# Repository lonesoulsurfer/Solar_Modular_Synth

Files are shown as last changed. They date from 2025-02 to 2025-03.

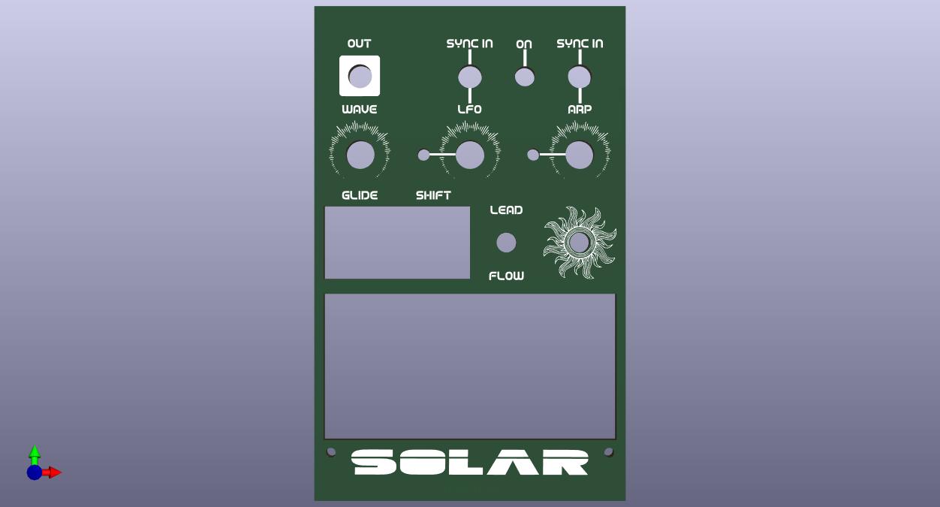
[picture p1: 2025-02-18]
Front Panel Design/Solar Front Panel.jpg

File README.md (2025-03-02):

g

# Solar Modular Synth
 A modular synth based around Arduino
First and foremost - a big shoutout to the creative team over at [Bleep Labs](https://bleeplabs.com/) for the original build which is called the Neblophone.

I wanted to be able to add some playability to the little modular synth that I'm putting together and after a extensive search on Google I stumbled on the Neblophone which I have re-named 'Solar' for this build.

The main changes that I have implemented are; I changed the stylus style keyboard over to actual momentary switches, I designed a front panel and custom PCB which can be used in Eurorack modules (or as a fun standalone synth) and lastly, added 2 sync inputs so you can connect it to other synths.

The sync inputs can be a little fiddily but once tuned in work great.  However, you don;t have to sync in the synth as you can just play it over the top of whatever you are jamming to.

So what are the features of the little synth?

– Eight waveforms

– Light controlled (Vactrol) analog low-pass filter with five adjustable LFO LED modes.

– Perfect tuning across six octaves.

– Adjustable temperament and key.

– Six arpeggio modes with adjustable rate.

The main goal with building this module is to create my own 'simple to build' modular synth. I wanted to keep everything as easy as possble with each module built with the following aims:

-   Can be powered by 9V (and 12V)

-   Easy to build with minimum components

-   Use Arduino to keep it simple (plus it helps to keep the components down and everything in tune)

-   Can fit into any modular synth Eurorck (include the ability to power the module via normal module power sources)

-   Has to sound great!

It's the first time that I have utilized cherry MX switches and I'm so glad that I used them! 
Lastly, as I have mentioned above, Solar makes a fun standalone synth and has been designed to be able to fit in Eurorack modules and powered via a Eurorack power supply!

I have also completed a step by step guide which you can find on Instructables

YouTube vid can be found below
https://www.youtube.com/watch?v=ggaYos6u02A

e

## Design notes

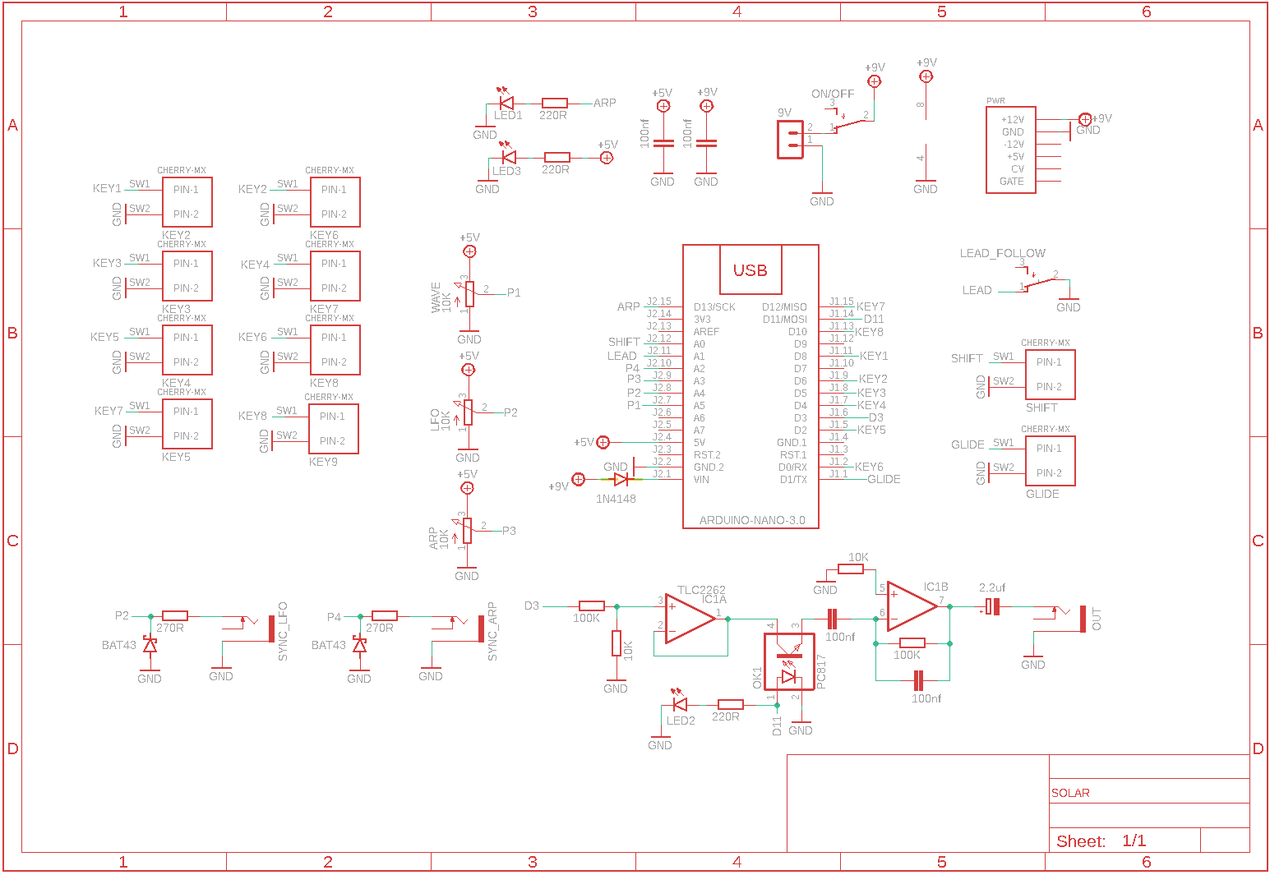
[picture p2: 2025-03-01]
schematic.png

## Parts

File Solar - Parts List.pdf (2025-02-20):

Part | Name | Type | Size | Value | Qty | Image Link

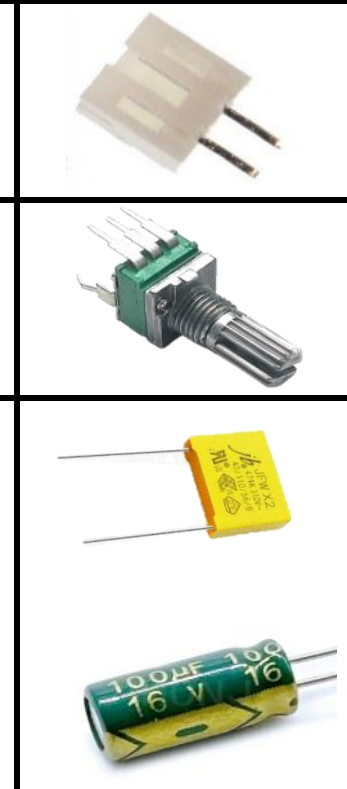
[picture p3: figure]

JST Connector | | Vertical - 2P | 2.0mm | | | Ali Express (https://www.aliexpress.com/w/wholesale-jst-connector-2.0-2P.html?spm=a2g0o.productlist.search.0)
Potentimeter | | Vertical | 9mm | 10K | 3 | Ali Express (https://www.aliexpress.com/w/wholesale-potentiometer-verticle-9mm.html)
Capacitor | | Polyester plastic electrolyte radial | | 100nf 2.2uf | 4 1 | Ali Express (https://www.aliexpress.com/w/wholesale-capacitor-polyester-plastic-.html) Ali Express (https://www.aliexpress.com/w/wholesale-capacitor-electrolytic-radial.html)
Diode | Bat43 1N4148 | Schottky | | | 2 1 | Ali Express (https://www.aliexpress.com/w/wholesale-bat43-diode.html?spm=a2g0o.detail.search.0) Ali Express (https://www.aliexpress.com/w/wholesale-1N4148-.html?spm=a2g0o.detail.search.0)
Swich | Cherry MX Cherry MX Caps Toggle switch | stitch type for PCB | | | 10 10 2 | Ali Express (https://www.aliexpress.com/w/wholesale-cherry-mx.html?spm=a2g0o.productlist.search.0) Ali Express (https://www.aliexpress.com/w/wholesale-cherry-mx-caps.html?spm=a2g0o.productlist.search.0) Ali Express (https://www.aliexpress.com/item/1005001510219617.html)
IC | TLC2262 | Op amp | 8 pin | | 1 | Ali Express (https://www.aliexpress.com/w/wholesale-TLC2262.html?spm=a2g0o.detail.search.0)

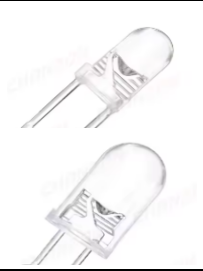
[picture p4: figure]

LED | | Any colour Yellow (or whatever colour you want) | 3mm 5mm | | 2 1 | Ali Express (https://www.aliexpress.com/w/wholesale-led-3mm.html?spm=a2g0o.detail.search.0) Ali Express (https://www.aliexpress.com/w/wholesale-5mm-led.html?spm=a2g0o.detail.search.0)

Part | Name | Type | Size | Value | Qty | Image Link

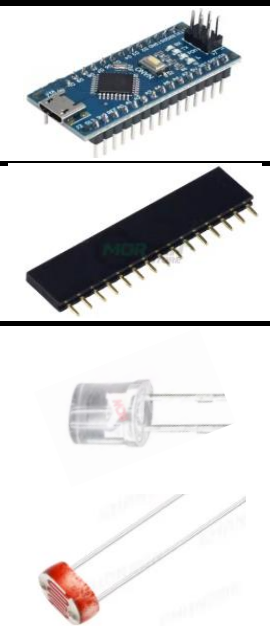
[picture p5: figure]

Arduino | Nano | Clone will work fine | | | 1 | Ali Express (https://www.aliexpress.com/w/wholesale-arduino-nano.html?spm=a2g0o.productlist.search.0)
Female Header Pins | | | 15 | | 2 | Ali Express (https://www.aliexpress.com/w/wholesale-header-pin-15-female.html?spm=a2g0o.detail.search.0)
Vactrol | LED photoresistor heat shrink | Flat head - white | 5mm 5 to 6mm | | 1 1 1 | Ali Express (https://www.aliexpress.com/w/wholesale-led-5mm-flat-head.html?spm=a2g0o.detail.search.0) Ali Express (https://www.aliexpress.com/w/wholesale-photoresistor.html?spm=a2g0o.detail.search.0) Ali Express (https://www.aliexpress.com/w/wholesale-heat-shrink-5mm.html?spm=a2g0o.detail.search.0)
Audio jack | PJ-301M | Vertical - pins should be PCB style | 3.5mm | | 3 | Ali Express (https://www.aliexpress.com/w/wholesale-PJ301M.html?spm=a2g0o.productlist.search.0)
Resistors | | metal film | 0.25W 1% | 100K 10K 220R 270R | 2 2 3 2 | Ali Express (https://www.aliexpress.com/w/wholesale-resistor-metal-film-assorted.html)

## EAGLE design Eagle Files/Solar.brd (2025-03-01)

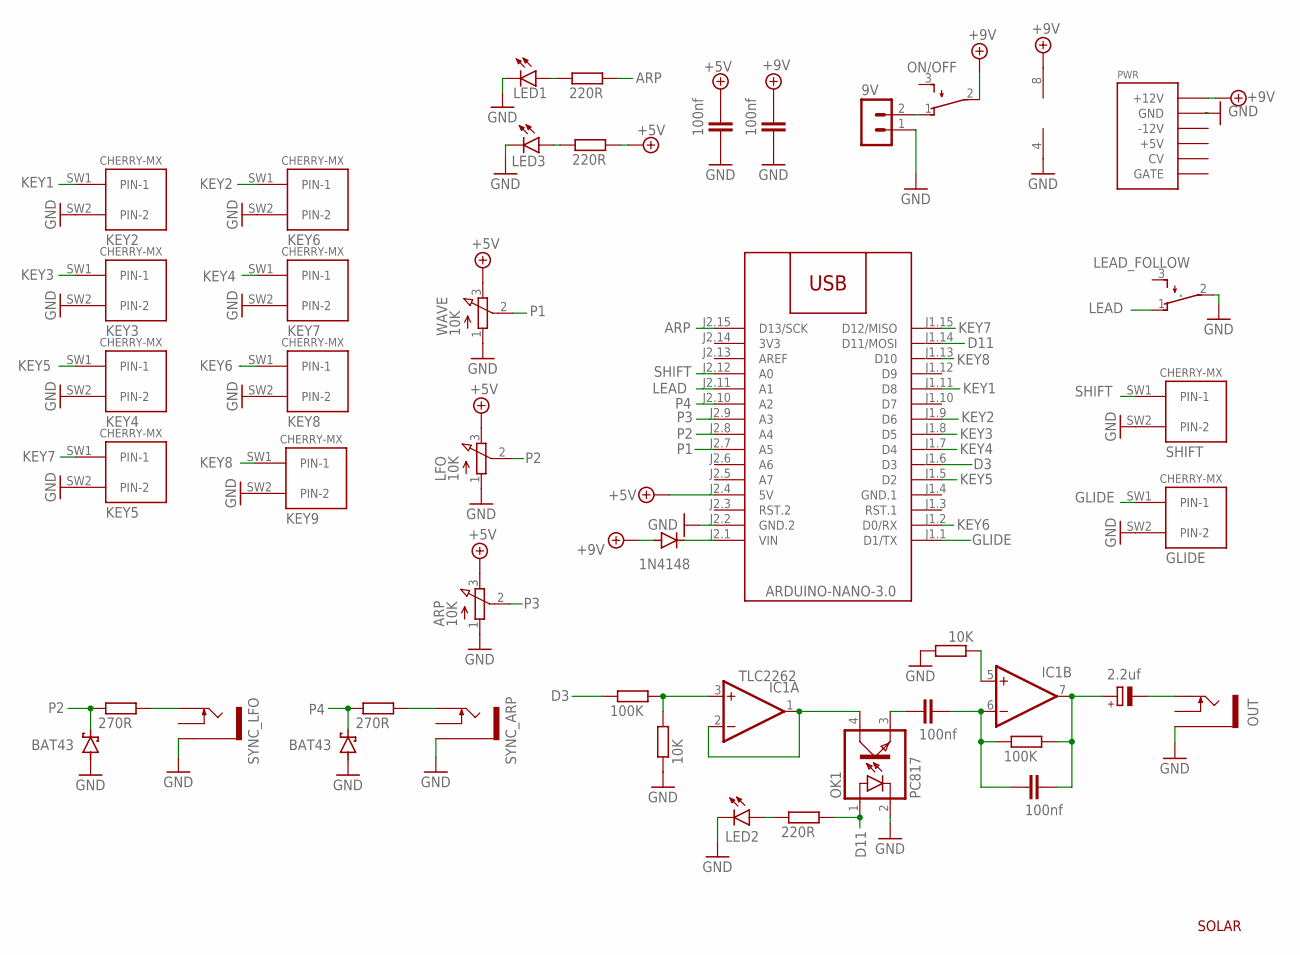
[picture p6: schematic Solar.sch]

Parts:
9V: B2B-PH-K-S
ARP: 10K; EVUFXL
C1, C2, C3, C5: 100nf; C050-024X044
C4: 2.2uf; E2,5-6E
D1, D3: BAT43; DO35-10
D2: 1N4148; DO35-7
GLIDE: CHERRY-MX
IC1: TLC2262; DIL08
KEY2, KEY3, KEY4, KEY5, KEY6, KEY7, KEY8, KEY9: CHERRY-MX
LEAD_FOLLOW: TL32PO; TL3XPO
LED1, LED2: LED3MM
LED3: LED5MM
LFO: 10K; EVUFXL
M1: ARDUINO-NANO-3.0
OK1: PC817; DIL04
ON/OFF: TL32PO; TL3XPO
OUT: THONKICONNNEW; WQP-PJ301M-12_JACK
PWR: POWER; POWER_16
R1, R3: 100K; 0207/10
R2, R4: 10K; 0207/10
R5, R8, R10: 220R; 0207/10
R6, R7: 270R; 0207/10
SHIFT: CHERRY-MX
SYNC_ARP: THONKICONNNEW; WQP-PJ301M-12_JACK
SYNC_LFO: THONKICONNNEW; WQP-PJ301M-12_JACK
WAVE: 10K; EVUFXL

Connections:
3V3: M1.J2.14 (3V3)
+5V: ARP.3 (E), C5.2, LFO.3 (E), M1.J2.4 (5V), R5.2, WAVE.3 (E)
+9V: C2.2, D2.A, IC1.8 (V+), ON/OFF.2, PWR.9 (+12V), PWR.10 (+12V)
ARP: M1.J2.15 (D13/SCK), R8.2
D3: M1.J1.6 (D3), R1.1
D11: M1.J1.14 (D11/MOSI), OK1.1 (A), R10.2
GLIDE: GLIDE.SW1 (PIN-1), M1.J1.1 (D1/TX)
GND: 9V.1, ARP.1 (A), C2.1, C5.1, D1.A, D3.A, GLIDE.SW2 (PIN-2), IC1.4 (V-), KEY2.SW2 (PIN-2), KEY3.SW2 (PIN-2), KEY4.SW2 (PIN-2), KEY5.SW2 (PIN-2), KEY6.SW2 (PIN-2), KEY7.SW2 (PIN-2), KEY8.SW2 (PIN-2), KEY9.SW2 (PIN-2), LEAD_FOLLOW.2, LED1.K (C), LED2.K (C), LED3.K (C), LFO.1 (A), M1.J2.2 (GND.2), OK1.2 (C), OUT.P$3_SLEEVE (SLEEVE), PWR.3 (GND), PWR.4 (GND), PWR.5 (GND), PWR.6 (GND), PWR.7 (GND), PWR.8 (GND), R2.1, R4.2, SHIFT.SW2 (PIN-2), SYNC_ARP.P$3_SLEEVE (SLEEVE), SYNC_LFO.P$3_SLEEVE (SLEEVE), WAVE.1 (A)
GND.1: M1.J1.4 (GND.1)
KEY1: KEY2.SW1 (PIN-1), M1.J1.11 (D8)
KEY2: KEY6.SW1 (PIN-1), M1.J1.9 (D6)
KEY3: KEY3.SW1 (PIN-1), M1.J1.8 (D5)
KEY4: KEY7.SW1 (PIN-1), M1.J1.7 (D4)
KEY5: KEY4.SW1 (PIN-1), M1.J1.5 (D2)
KEY6: KEY8.SW1 (PIN-1), M1.J1.2 (D0/RX)
KEY7: KEY5.SW1 (PIN-1), M1.J1.15 (D12/MISO)
KEY8: KEY9.SW1 (PIN-1), M1.J1.13 (D10)
LEAD: LEAD_FOLLOW.1 (O), M1.J2.11 (A1)
unnamed: LED1.A, R8.1
unnamed: 9V.2, ON/OFF.1 (O)
unnamed: IC1.3 (+IN), R1.2, R2.2
unnamed: R7.2, SYNC_LFO.P$1_TIP (TIP)
unnamed: IC1.1 (OUT), IC1.2 (-IN), OK1.4 (COL)
unnamed: C1.1, OK1.3 (EMIT)
unnamed: C1.2, C3.1, IC1.6 (-IN), R3.1
unnamed: IC1.5 (+IN), R4.1
unnamed: C3.2, C4.+, IC1.7 (OUT), R3.2
unnamed: C4.-, OUT.P$1_TIP (TIP)
unnamed: LED3.A, R5.1
unnamed: R6.2, SYNC_ARP.P$1_TIP (TIP)
unnamed: LED2.A, R10.1
unnamed: D2.C, M1.J2.1 (VIN)
P1: M1.J2.7 (A5), WAVE.2 (S)
P2: D1.C, LFO.2 (S), M1.J2.8 (A4), R7.1
P3: ARP.2 (S), M1.J2.9 (A3)
P4: D3.C, M1.J2.10 (A2), R6.1
SHIFT: M1.J2.12 (A0), SHIFT.SW1 (PIN-1)

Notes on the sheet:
SOLAR

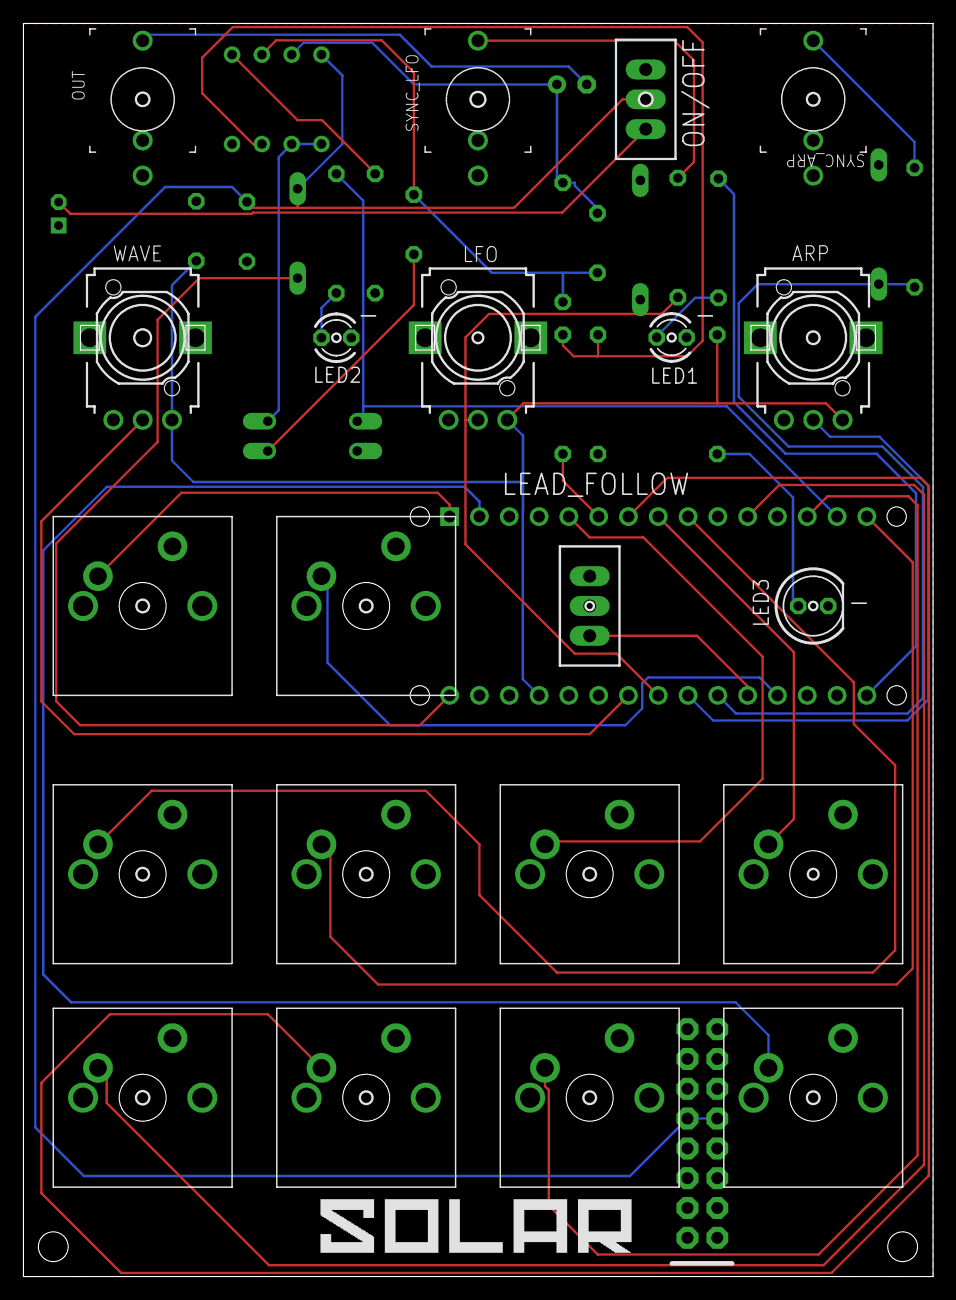
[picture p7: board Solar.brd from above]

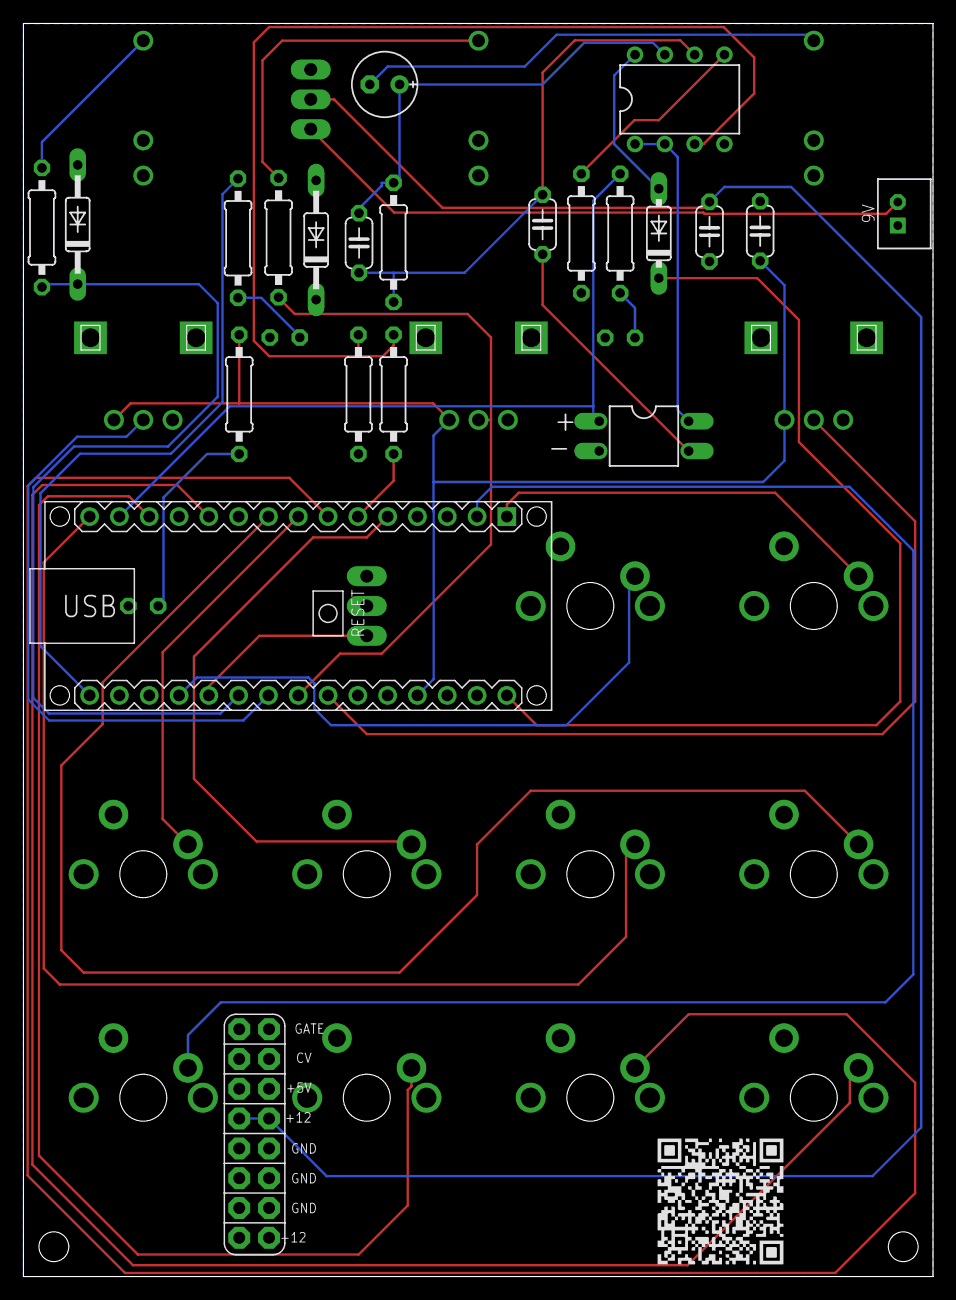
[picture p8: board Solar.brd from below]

Board: 2 copper layers, 77.5 x 106.8 mm, 43 parts (22 on the bottom side), 35 nets.

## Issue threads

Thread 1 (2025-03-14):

(Feature request) Add some way to play the device with an external controller.

rl2939, 2025-03-14:
## Problem:

Right now, the only way to play _Solar_ is by pressing the keys on the device. It is not possible to play the device from a keyboard or external sequencer.

## Solution:
Add ports to play the device from a keyboard or external sequencer. Some ideas include:
- 1v/oct and gate in ports
- MIDI port

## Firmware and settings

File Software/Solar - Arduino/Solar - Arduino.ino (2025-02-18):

/*

 NEBULOPHONE code v11 by Dr. Bleep
 
This code has not changed much since it was released mid 2011. It's very gnarly and amature and kinda embarrassing now but it did the thing!
It was my first big Arduino project and I coundn't have done it without these resources:

DDS:
 http://mouro.info/signal-generator-using-arduino-and-dds/
 http://interface.khm.de/index.php/lab/experiments/arduino-dds-sinewave-generator/
 http://www.analog.com/library/analogdialogue/archives/38-08/dds.html

Setting up timers.
 http://www.cs.mun.ca/~rod/Winter2007/4723/notes/timer0/timer0.html
 http://arcfn.com/2009/07/secrets-of-arduino-pwm.html
 http://blog.wingedvictorydesign.com/2009/05/29/generate-real-time-audio-on-the-arduino-using-pulse-code-modulation/2/

Also good to know:
 http://billgrundmann.wordpress.com/2009/03/03/to-use-or-not-use-writedigital/

BUT
My DIY noise guides and classes on using the Teensy to make synths are a better place to start these days. 
https://github.com/BleepLabs/Bleep-wiki/wiki
https://github.com/BleepLabs/dadageek-April-21/wiki

 */
#include <avr/pgmspace.h>
//#include <MemoryFree.h>

unsigned long chromatic[] = {

  2750, 2914, 3087, 3270, 3465, 3671, 3889, 4120, 4365, 4625, 4900, 5191, 5500, 5827, 6174, 6541, 6930, 7342, 7778,
  8241, 8731, 9250, 9800, 10383, 11000, 11654, 12347, 13081, 13859, 14683, 15556, 16481, 17461, 18500, 19600,
  20765, 22000, 23308, 24694, 26163, 27718, 29367, 31113, 32963, 34923, 36999, 39200, 41531, 44000, 46616, 49388,
  52325, 55437, 58733, 62225, 65926, 69846, 73999, 78399, 83061, 88000, 93233, 98777, 104650, 110873, 117466,
  124451, 131851, 139691, 147998, 156798, 166122, 176000, 186466, 197553, 209300, 221746, 234932, 248902, 263702,
  279383, 295996, 313596, 332244, 352000, 372931, 395107, 418601

};
int scale[] = {
  0, 2, 4, 5, 7, 9, 11, 12, 14, 16, 17, 19, 21, 23, 24, 26, 28, 29, 31, 33, 35, 36, 38, 40, 41, 43, 45, 47, 48, 50, 52, 53, 55, 57, 59, 60, 62, 64
};


unsigned long counter, cprev1, cprev2;
unsigned long freq, freq2, keyfreq;

byte n = 1;
int keypress, kh, prevkh2, prevkeypress2;
int prevn;
int prevkeypress, prevattackmode;
int keyr1, keyr0, keyra, keyrw, keyrw2;
int waveselect, subwaveselect, prevwavepot;
int r, r2;
int i = 1;
long prev;
long prev4;

int irin;
int irout;
long irtempo;
int ir = 0;
long previrtempo = 1;
long previr = 0;
int arpselect;
byte count = 0;
int a = 0;
int key = 1;
int d;
int s;
int lforate;
int lforateC;
int lfo = 0;
int l = 0;
int j = 10;
int r3;
byte dronemode = 3;
byte dronemodebutton, prevdronemodebutton;
int irtempomod;
int irswitch;
int arprate = 10;
int arprateF;
int arprateL;
int keyoffset = 0;

byte scan = 1;
byte shiftbutton;
byte prevshiftbutton;
int shift = 0;
int maxrelease = 250;
int maxbrightness = 84;
int keym;
int prevarprateF;
int glide = 3;
byte keyp;
byte keyc;
int remember[2];
int h = 0;
long frequencyout;
long frequencyp;
long g;
long  f;
int gliderate;
long prev9;
int k;
int glidebutton;
int prevglidebutton;
int c = 1;
int b;
int maxwaveindex = 15;
int temp;
int release, releasem, releaseb;
int releaselength;
int ampholder = 1;
int previrin;
static int oscc, oscx, oscy, oscz, oscb, oscxb;
float amp = 1;
int wavepot, arppot, lfopot;
int himap, lowmap, lowf, hif, himap2, lowmap2;
int pwmPin = 3;
int ampm, ampb, read0, read1;
int arpcount, arp;
volatile unsigned long accumulator = 0;
volatile unsigned long accumulator2 = 0;
volatile unsigned long accumulator3 = 0;
volatile unsigned long accumulator4 = 0;
volatile unsigned long accumulator5 = 0;
volatile unsigned long increment = 0;
volatile unsigned long increment2 = 0;
volatile unsigned long increment3 = 0;
volatile unsigned long increment4 = 0;
volatile unsigned long increment5 = 0;
volatile unsigned long increment6 = 0;
volatile unsigned long increment7 = 0;


long prev8;
int incrementb = 0;
unsigned long holder4;
unsigned long holder3;
unsigned long holder2;
unsigned long holder;
int offx;
byte index = 0;
byte index2 = 0;
byte index3 = 0;
byte index4 = 0;
byte indexb = 0;
byte index5 = 0;
long frequency, frequencyc, frequency2, frequency2c, frequencyouta, frequencycs, frequencyps, temppot;
int rint, indexi;
int noise = 0;
int wrc, cnw, apot, waveB, waveoff;
float bpotf;
int drone;
int acc = 8;
int oscmode = 1;
int ircount;
//long tempobank[4];
int aread, oscsel;
int oscswitch = 1;
uint16_t osc, oscj, uosc, wr, wr2, rosc, bswitch;
int xpot;
int up = 1;
int tempermentbutton, shiftcount;
int temperment = 1;
int offsetpot = 5;
int keypot = 0;
int keypotm = 0;
int tunemode = 0;
int attackmode;
int attacklength;
int upa = 1, upb = 1, upc = 1;
int toplatcha = 0;
int attackon = 0;
unsigned long prev2, prev3;
int keydown, counta, prevkeydown;
//long tune;
int maxarp = 306;
unsigned long frequencya, frequencyw, frequencyw2;
int attackp;
long attacka, attackw, wavemod;
long gstep;
unsigned int lfsr = 1;
unsigned int lfsr2 = 1;
unsigned bitholder, bitholder2;
volatile byte icnt1, icnt2, ms, noisecount;
int keysb, keysd, keypressb, keypressd, prevkeypressb, prevkeypressd, prevkh;
int scount;
int gauge, spd;
long sprev;
int restbutton = 1,      recordbutton = 1, prevrestbutton,      prevrecordbutton ;
int record, rcount = 1, recordlatch, prevrcount, resta = 0;
int recordbank[32] = {2, 63, 5, 63, 10, 63, 5, 63, 1, 63, 63, 63, 10, 63, 63, 63};
int rplace, rest = 0, rstop = 8, prevrecord;
byte bhold;
volatile long whatok, whatno;
int i1, i2, i3, i4, tria;
byte b1, b2, b3, b4;
int epot, dswitch, noisekey, rarp;
long fpot, bpot, gpot, recordinput;
long thecount;
const  char  waveTable[] PROGMEM =


{
  0, 0, 0, 0, 0, 0, 0, 0, 0, 0, 0, 0, 0, 0, 0, 0, 0, 0, 0, 0, 0, 0, 0, 0, 0, 0, 0, 0, 0, 0, 0, 0, 0, 0, 0, 0, 0, 0, 0, 0, 0, 0, 0, 0, 0, 0, 0, 0, 0, 0, 0, 0, 0, 0, 0, 0, 0, 0, 0, 0, 0, 0, 0, 0,
  0, 0, 0, 0, 0, 0, 0, 0, 0, 0, 0, 0, 0, 0, 0, 0, 0, 0, 0, 0, 0, 0, 0, 0, 0, 0, 0, 0, 0, 0, 0, 0, 0, 0, 0, 0, 0, 0, 0, 0, 0, 0, 0, 0, 0, 0, 0, 0, 0, 0, 0, 0, 0, 0, 0, 0, 0, 0, 0, 0, 0,
  0, 0, 0, 0, 0, 0, 0, 0, 0, 0, 0, 0, 0, 0, 0, 0, 0, 0, 0, 0, 0, 0, 0, 0, 0, 0, 0, 0, 0, 0, 0, 0, 0, 0, 0, 0, 0, 0, 0, 0, 0, 0, 0, 0, 0, 0, 0, 0, 0, 0, 0, 0, 0, 0, 0, 0, 0, 0, 0, 0, 0,
  0, 0, 0, 0, 0, 0, 255, 255, 255, 255, 255, 255, 255, 255, 255, 255, 255, 255, 255, 255, 255, 255, 255, 255, 255, 255, 255, 255, 255, 255, 255, 255, 255, 255,
  255, 255, 255, 255, 255, 255, 255, 255, 255, 255, 255, 255, 255, 255, 255, 255, 255, 255, 255, 255, 255, 255, 255, 255, 255, 255, 255, 255, 255, 255, 255,
  255, 255, 255, 255, 255, 255, 255, 255, 255, 255, 255, 255, 255, 255, 255, 255, 255, 255, 255, 255, 255, 255, 255, 255, 255, 255, 255, 255, 255, 255, 255,
  255, 255, 255, 255, 255, 255, 255, 255, 255, 255, 255, 255, 255, 255, 255, 255, 255, 255, 255, 255, 255, 255, 255, 255, 255, 255, 255, 255, 255, 255, 255,
  255, 255, 255, 255, 255, 255,

  1, 1, 2, 3, 4, 5, 6, 7, 8, 9, 10, 11, 12, 13, 14, 15, 16, 17, 18, 19, 20, 21, 22, 23, 24, 25, 26, 27, 28, 29, 30, 31, 32, 33, 34, 35, 36, 37, 38, 39, 40, 41, 42, 43, 44, 45, 46, 47, 48, 49, 50, 51, 52, 53, 54, 55, 56, 57, 58, 59, 60,
  61, 62, 63, 64, 65, 66, 67, 68, 69, 70, 71, 72, 73, 74, 75, 76, 77, 78, 79, 80, 81, 82, 83, 84, 85, 86, 87, 88, 89, 90, 91, 92, 93, 94, 95, 96, 97, 98, 99, 100, 101, 102, 103, 104, 105, 106, 107, 108, 109, 110, 111, 112, 113,
  114, 115, 116, 117, 118, 119, 120, 121, 122, 123, 124, 125, 126, 127, 128, 129, 130, 131, 132, 133, 134, 135, 136, 137, 138, 139, 140, 141, 142, 143, 144, 145, 146, 147, 148, 149, 150, 151, 152, 153, 154, 155, 156,
  157, 158, 159, 160, 161, 162, 163, 164, 165, 166, 167, 168, 169, 170, 171, 172, 173, 174, 175, 176, 177, 178, 179, 180, 181, 182, 183, 184, 185, 186, 187, 188, 189, 190, 191, 192, 193, 194, 195, 196, 197, 198, 199,
  200, 201, 202, 203, 204, 205, 206, 207, 208, 209, 210, 211, 212, 213, 214, 215, 216, 217, 218, 219, 220, 221, 222, 223, 224, 225, 226, 227, 228, 229, 230, 231, 232, 233, 234, 235, 236, 237, 238, 239, 240, 241, 242,
  243, 244, 245, 246, 247, 248, 249, 250, 251, 252, 253, 254,

  1, 3, 5, 7, 9, 11, 13, 15, 17, 19, 21, 23, 25, 27, 29, 31,
  33, 35, 37, 39, 41, 43, 45, 47, 49, 51, 53, 55, 57, 59, 61, 63, 65,
  67, 69, 71, 73, 75, 77, 79, 81, 83, 85, 87, 89, 91, 93, 95, 97, 99,
  101, 103, 105, 107, 109, 111, 113, 115, 117, 119, 121, 123, 125, 127, 129, 131, 133,
  135, 137, 139, 141, 143, 145, 147, 149, 151, 153, 155, 157, 159, 161, 163, 165, 167,
  169, 171, 173, 175, 177, 179, 181, 183, 185, 187, 189, 191, 193, 195, 197, 199, 201,
  203, 205, 207, 209, 211, 213, 215, 217, 219, 221, 223, 225, 227, 229, 231, 233, 235,
  237, 239, 241, 243, 245, 247, 249, 251, 253, 255, 254, 252, 250, 248, 246, 244, 242,
  240, 238, 236, 234, 232, 230, 228, 226, 224, 222, 220, 218, 216, 214, 212, 210, 208,
  206, 204, 202, 200, 198, 196, 194, 192, 190, 188, 186, 184, 182, 180, 178, 176, 174,
  172, 170, 168, 166, 164, 162, 160, 158, 156, 154, 152, 150, 148, 146, 144, 142,
  140, 138, 136, 134, 132, 130, 128, 126, 124, 122, 120, 118, 116, 114, 112, 110, 108,
  106, 104, 102, 100, 98, 96, 94, 92, 90, 88, 86, 84, 82, 80, 78, 76, 74, 72, 70, 68, 66,
  64, 62, 60, 58, 56, 54, 52, 50, 48, 46, 44, 42, 40, 38, 36, 34, 32, 30, 28, 26, 24, 22,
  20, 18, 16, 14, 12, 10, 8, 6, 4, 2, 0,



};

void setup(void)

{

  //Serial.begin(9600);
  pinMode(1, INPUT);
  pinMode(0, INPUT);

  pinMode(2, INPUT);
  pinMode(4, INPUT);
  pinMode(5, INPUT);
  pinMode(6, INPUT);
  pinMode(7, INPUT);
  pinMode(8, INPUT);
  pinMode(9, INPUT);
  pinMode(10, INPUT);
  pinMode(12, INPUT);
  pinMode(14, INPUT);
  pinMode(15, INPUT);
  pinMode(3, OUTPUT);
  pinMode(13, OUTPUT); // IR out
  pinMode(11, OUTPUT); // LFO LED out

  digitalWrite(1, HIGH);
  digitalWrite(0, HIGH);

  digitalWrite(2, HIGH);
  digitalWrite(4, HIGH);
  digitalWrite(5, HIGH);
  digitalWrite(6, HIGH);
  digitalWrite(7, HIGH);
  digitalWrite(8, HIGH);
  digitalWrite(9, HIGH);
  digitalWrite(10, HIGH);
  digitalWrite(12, HIGH);
  digitalWrite(14, HIGH);
  digitalWrite(15, HIGH);

  randomSeed(analogRead(5));


  if (digitalRead(14) == LOW) {
    oscswitch = 2;
  }
  else oscswitch = 1;

#define cbi(sfr, bit) (_SFR_BYTE(sfr) &= ~_BV(bit))
#define sbi(sfr, bit) (_SFR_BYTE(sfr) |= _BV(bit))


  sbi (TIMSK2, TOIE2);

  sbi (TCCR2B, CS20);
  cbi (TCCR2B, CS21);
  cbi (TCCR2B, CS22);

  cbi (TCCR2A, COM2A0);  // clear Compare Match
  sbi (TCCR2A, COM2A1);
  sbi (TCCR2A, COM2B1);

  sbi (TCCR2A, WGM20);  // Mode 1  / Phase Correct PWM
  cbi (TCCR2A, WGM21);
  cbi (TCCR2B, WGM22);

}


////////////////////////////////////////////////////////////////////////////////////////////////////////////////////
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
void loop(){

DDS(  );
CONTROLS ();
KEYS ();
GLIDE();
SHIFT();
WAVESELECT();

ARP();
LFO();
RECORD();

}

////////////////////////////////////////////////////////////////// ARP

void ARP(){

  if (arppot <5){
    //  remember[0] = key;
    remember[1] = key;
    count=0;  
    //a=0;

  }
  if (arppot >=5 && arppot<170)  {

    arprateL = map(arppot, 5, 170, maxarp, 1);
    arprateL = constrain(arprateL, 1 , maxarp);  
    arprateF = map(arppot, 5, 170, 4, 1);
    arprateF = constrain(arprateL, 1 , 4);  

    if (count==0){
      remember[0] = key;
      remember[1] = key +0;
      toplatcha=0;
    }
    else if (count==1){
      remember[0] = key;
      remember[1] = key +2;
      toplatcha=0;
    }
    else if (count>=2){ 
      count=0;
    }

  }


  if (arppot >=170 && arppot<340)  {

    arprateL = map(arppot, 170, 340, maxarp , 1);
    arprateL = constrain(arprateL, 1 , maxarp);  
    arprateF = map(arppot, 170, 340, 1, 4);
    arprateF = constrain(arprateF, 1 , 4);  


    if (count==0)      {
      remember[0] = key;
      remember[1] = key +0;

    }
    else if (count==1)      {
      remember[0] = key;
      remember[1] = key -1;

    }
    else if (count==2)      {        
      remember[0] = key;
      remember[1] = key -2; 

    }
    else if (count>=3)      {        
      count=0;

    }
  }



  if (arppot >=340 && arppot<510)  {

    arprateL = map(arppot, 340, 510, maxarp , 1);
    arprateL = constrain(arprateL, 1 , maxarp);  
    arprateF = map(arppot, 340, 510,  1, 4);
    arprateF = constrain(arprateF, 1 , 4);  

    if (count<8)
    {
      remember[0] = key;
      remember[1] = key +count;

    }
    else if (count>=8)
    {
      // a=0; 
      count=0;
    }
  }

  if (arppot >=510 && arppot<680)  {


    arprateL = map(arppot, 510, 680, maxarp , 1);
    arprateL = constrain(arprateL, 1 , maxarp);  
    arprateF = map(arppot, 510, 680,  1, 4);
    arprateF = constrain(arprateF, 1 , 4);  

    if (count<8)
    {
      remember[0] = key;
      remember[1] = key+8 -count;

    }
    else if (count>=8)
    {
      // a=0; 
      count=0;
    }
  }
  if (arppot >=680 && arppot<850)  {
    
    
    
    recordlatch=0;
    resta=0;
    rest=0;
    arprateL = map(arppot, 680, 850,  maxarp , 1);
    arprateL = constrain(arprateL, 1 , maxarp);  
    arprateF = map(arppot, 680, 850,  1, 4);
    arprateF = constrain(arprateF, 1 , 4);  


    if (count==0)
    {    

      remember[0] = key;
      remember[1] = key+rarp;

    }
    else if (count==1)
    { 
       rarp=  random(-8,12);
       
      remember[0] = key;
      remember[1] = key +0;

    }
    else if (count>=2)
    {
      count=0;
    }

  }

  if (arppot >=850 && arppot<1020) {
    recordlatch=0;
    rplace=0;
    rcount=0;
    record=0;

    record=0;
    arprateL = map(arppot, 850, 1020,  maxarp , 1);
    arprateL = constrain(arprateL, 1 , maxarp);  
    arprateF = map(arppot, 850, 1020,  1, 4);
    arprateF = constrain(arprateF, 1 , 4);  

    if (count<rstop)
    {

      if (recordbank[count]==63){
        
        resta=1;
        remember[0] = key;
        remember[1] = key;
      }

      if (recordbank[count]!=63){
        resta=0;
        remember[0] = key;
        remember[1] = key+recordbank[count];
      }

    }

    if (count>=rstop)
    {
      count=0;
    }


  }

  if (arppot >=1020){

   // count=0;
   // arprateL=0;
   // arprateF=0;
    recordlatch=1;
    digitalWrite(13, LOW);  
    //arprateL=0;
    //arprateF=0;
    resta=0;

  }

  if (prevarprateF != arprateF){
    previrtempo=0;
  }

  prevarprateF = arprateF;


}




void IR(){
   ////////////////////////////////////////////////////////////////// IR
  // All of the Andromeda Space Rocker Kits can communicate via IR. The Nebulophone can sync it's arpeggiator to a multiple
  // of the IR clock rate. This is done but simply reading the analog input conected to the detector and measuring the time
  // between peaks. There are some sync issuse to work, though. I believe the rate is read correctly but sometimes the arp
  // speed can lag.

 // if (tunemode!=1){
    if (irswitch == 0){

      irin = (analogRead(2));

      if (irin > 5 && previrin <=5){

        irtempo = millis() - previrtempo; 
        previrtempo = millis();
        ir=1;

        //      irsub();
      }

      else {
        ir=0;   
      }

      previrin=irin; 
      arprate = irtempo / arprateF;

    }



    else if (irswitch == 1){
      arprate = arprateL;

    }



    if (millis() - prev8 >= arprate ) {
      prev8 = millis();

    //  r3 = (lfsr2>>12)-8;

      count++;   
PORTB |= _BV(5);

    }
    
    else {
    PORTB &= ~_BV(5);
    
    }
  }

void KEYS(){
  
// the order of the pins from lowest note is 15,16,18,2,4,6,11,12,13,14
  j++;//
  if (j>63){
    //dfreqc=(analogRead(4))*8;         
    //dfreqf=(analogRead(5)/8); 
  }

  keysb = (PINB & B00010111);
  keysd= (PIND &   B11110101);

  switch (keysb){
  case B10101:
    kh=1;
    keypress=1;
    keypressb=1;
    break;

  case B10011:
    kh=2;   
    keypress=1;   
    keypressb=1;
    break;

  case B111:
    kh=3;   
    keypress=1;   
    keypressb=1;
    break;

  case B10110:
    kh=10;   
    keypress=1;   
    keypressb=1;
    break;

  default: 
    keypressb=0;   
    break;
  }

  switch (keysd){
  case B11110100:
    kh=4;
    keypress=1;
    keypressd=1;
    break;

  case B11110001:
    kh=5;   
    keypress=1;   
    keypressd=1;
    break;

  case B11100101:
    kh=6;   
    keypress=1;   
    keypressd=1;
    break;

  case B11010101:
    kh=7;   
    keypress=1;   
    keypressd=1;
    break;

  case B10110101:
    kh=8;   
    keypress=1; 
    keypressd=1;  
    break;

  case B1110101:
    kh=9;   
    keypress=1; 
    keypressd=1;      
    break;

  default: 

    keypressd=0;  
    break;
  }

  key = kh;

  if (keypressd==0 && keypressb==0)
  {
    keypress=0;
  }

  if (kh != prevkh || keypress!=prevkeypress){

    if (keypress == 1) {
      count=0;
      remember[0] = prevkh;
      release=255;
              releaseb=255;
      remember[1] = key;
      keydown =1;
      scan=0;
    }   

    prevkh = kh;
    prevkeypress=keypress;
    prevkeydown=keydown;
  }

  if (keypress == 0) {

    keydown =0;
    if (millis() - prev > releaselength ) {       
      prev = millis();
      if (releaselength<20){
                releaseb-=4;
        if (release > 5){
          release-=(((release))*.3);
        }

        if (release <= 10){
                  releaseb-=4;
          release =0;
          ampholder=1;
        }
      }
      if (releaselength>=20){
        releaseb-=4;
        if (release > 5){
          release-=(((release))*.02);
        }

        if (release <= 10){
          release =0;
          ampholder=1;
        }
      }




    }

  }

  
}

void LFO(){
  
 ////////////////////////////////////////////////////////////////// LFO
  // The LFO outputs analog levels through the PWM in a more traditional way but since it's using
  // pin 11 with is also on Timer 1, it will sound much better since the LED won't actually be 
  // blinking at 500 Hz.
  // Only one pot is used to control mode as well as rate. Inside each mode a differnt output
  // is performed based on lforateC.
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

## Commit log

2025-02-18 updated names
    [Nebulophone Modular Kicad.kicad_pcb]
2025-03-01 Update Solar PCB - Gerber File.zip
2025-03-01 file updates
    [Solar PCB - Modular.brd, Solar.brd, Solar.sch]

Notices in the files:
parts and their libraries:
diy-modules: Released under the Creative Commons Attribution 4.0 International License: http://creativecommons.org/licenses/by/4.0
